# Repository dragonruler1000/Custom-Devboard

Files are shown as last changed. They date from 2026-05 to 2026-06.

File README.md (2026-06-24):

# Primortia Devboard
This is a custom rp2040 devboard that i wanted to make so i could use a custom board instead of a pico for a few projects and because i thought that it would be a fun challange and a way to test my knowlage of how to route a trace properly. sense it is PCBA the only parts that are soldered after it arrives is the pins on the edges.

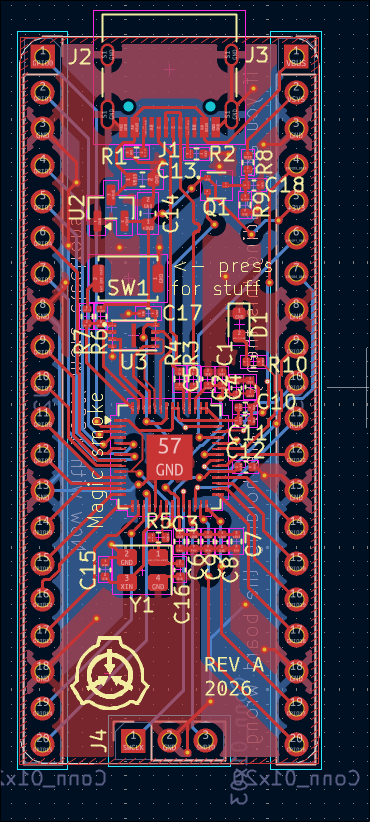
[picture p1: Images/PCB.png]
keyboard PCB


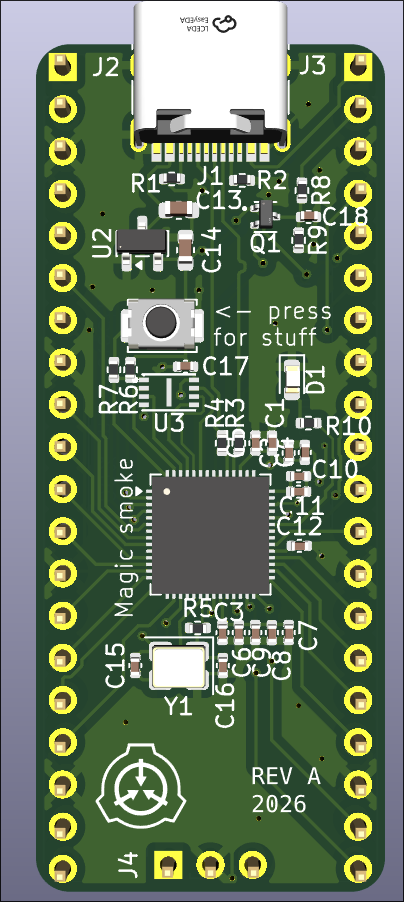
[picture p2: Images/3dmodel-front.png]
3d model front

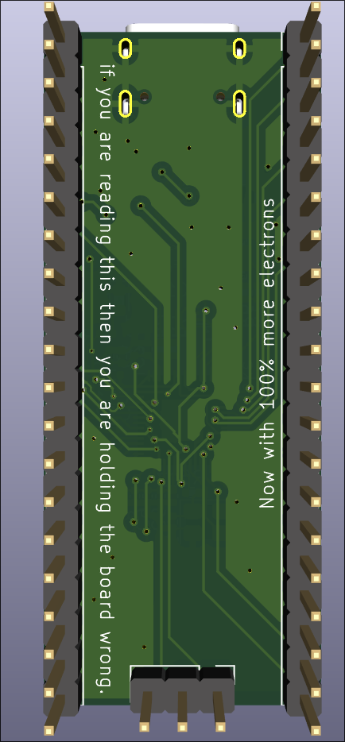
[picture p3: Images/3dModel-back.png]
3d model front


BOM:
| Item Count | item name | Unit price $ | Total Price* | Price with discounts* | Link | Running total $* | Running total with coupons* | part number | Notes |
|---|---|---|---|---|---|---|---|---|---|
| 2 | rp2040 | 0.98 | 1.96 | 1.96 | https://jlcpcb.com/partdetail/RaspberryPi-RP2040/C2040 | 2.08 | 2.08 | 1 | |
| 2 | USB-C port | 0.18 | 0.36 | 0.36 | https://jlcpcb.com/partdetail/Korean_HropartsElec-TYPE_C_31_M12/C165948  | 2.46 | 2.46 | 2 | |
| 2 | crystal oscillator | 0.07 | 0.14 | 0.14 | https://jlcpcb.com/partdetail/YXC_CrystalOscillators-X322512MSB4SI/C9002 | 2.61 | 2.61 | 3 | |
| 2 | flash memory | 0.69 | 1.38 | 1.38 | https://jlcpcb.com/partdetail/3384470-IS25WP016D_JULETR/C2976734 | 4.07 | 4.07 | 4 | |
| 2 | bush button | 0.06 | 0.12 | 0.12 | https://jlcpcb.com/partdetail/XUNPU-TS_1088AR02016/C720477 | 4.2 | 4.2 | 5 | |
| 2 | Schottky diode | 0.04 | 0.08 | 0.08 | https://jlcpcb.com/partdetail/TECHPUBLIC-DMG1012T/C2830301 | 4.28 | 4.28 | 6 | |
| 2 | LDO | 0.63 | 1.26 | 1.26 | https://jlcpcb.com/partdetail/MicrochipTech-MCP1700T_1202ETT/C144202 | 5.62 | 5.62 | 7 | |
| 4 | 1uF capacitor | 0.01 | 0.04 | 0.04 | https://jlcpcb.com/partdetail/53938-CL05A105KA5NQNC/C52923 | 5.66 | 5.66 | 8 | |
| 22 | 0.1uf capacitor | 0.01 | 0.22 | 0.22 | https://jlcpcb.com/partdetail/1877-CL05B104KO5NNNC/C1525 | 5.89 | 5.89 | 9 | |
| 4 | 33pF capacitors | 0.01 | 0.04 | 0.04 | https://jlcpcb.com/partdetail/1914-0402CG330J500NT/C1562 | 5.93 | 5.93 | 10 | |
| 2 | 1nF Capacitor | 0.01 | 0.02 | 0.02 | https://jlcpcb.com/partdetail/1875-0402B102K500NT/C1523 | 5.95 | 5.95 | 10 | |
| 4 | 10uF Capacitors | 0.01 | 0.04 | 0.04 | https://jlcpcb.com/partdetail/20411-CL10A106KP8NNNC/C19702 | 5.99 | 5.99 | 10 | |
| 2 | LED | 0.01 | 0.02 | 0.02 | https://jlcpcb.com/partdetail/CHONGTIAN-CT_1608UGCP4/C52675989 | 6.01 | 6.01 | 10 | |
| 2 | 470R Resistors | 0.01 | 0.02 | 0.02 | https://jlcpcb.com/partdetail/25860-0402WGF4700TCE/C25117 | 6.03 | 6.03 | 8 | |
| 4 | 5.1k Resistors | 0.01 | 0.04 | 0.04 | https://jlcpcb.com/partdetail/26648-0402WGF5101TCE/C25905 | 6.07 | 6.07 | 9 | |
| 4 | 1k Resistors | 0.01 | 0.04 | 0.04 | https://jlcpcb.com/partdetail/12256-0402WGF1001TCE/C11702 | 6.11 | 6.11 | 10 | |
| 4 | 27 Resistors | 0.01 | 0.04 | 0.04 | https://jlcpcb.com/partdetail/Sunway-SC0402J27R0F2ANRH/C5141043 | 6.15 | 6.15 | 8 | |
| 2 | 10K Resistors | 0.01 | 0.02 | 0.02 | https://jlcpcb.com/partdetail/26487-0402WGF1002TCE/C25744 | 6.17 | 6.17 | 9 | |
| 2 | 100K Resistors | 0.01 | 0.02 | 0.02 | https://jlcpcb.com/partdetail/26484-0402WGF1003TCE/C25741 | 6.19 | 6.19 | 10 | |
| 2 | 200K Resistors | 0.01 | 0.02 | 0.02 | https://jlcpcb.com/partdetail/26507-0402WGF2003TCE/C25764 | 6.21 | 6.21 | 10 | |
| 4 | 1x20 pin header | 1.04 | 4.16 | 4.16 | https://www.digikey.com/en/products/detail/adam-tech/PH1-20-UA/9830398 | 10.62 | 10.62 | 12 | |
| 1 | PCB | 3.1 | 3.1 | 3.1 | https://jlcpcb.com/partdetail/CHONGTIAN-CT_1608UGCP4/C52675989 | 13.91 | 13.91 | 10 | |
| 1 | PCBA – parts price | 33.65 | 33.65 | 33.65 | https://jlcpcb.com/ | 49.58 | 49.58 | 10 | |
| 1 | JLCPCB Shipping | 7.29 | 7.29 | 3 | https://jlcpcb.com/ | 57.31 | 52.76 | 10 | |
| 1 | Digikey Shipping | 6.99 | 6.99 | 6.99 | https://www.digikey.com | 64.72 | 60.17 | 10 | |
| | | | | | | | | | |
| | | | | | | | *Rounded to two decimal places | | |

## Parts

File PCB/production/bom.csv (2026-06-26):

Designator | Footprint | Quantity | Value | LCSC Part #
C1, C10 | 0402 | 2 | 1uF
C11, C12, C17, C2, C3, C4, C5, C6, C7, C8, C9 | 0402 | 11 | 0.1uF
C13, C14 | 0603 | 2 | 10uF
C15, C16 | 0402 | 2 | 33pF
C18 | 0402 | 1 | 1nf
D1 | 0603 | 1 | Green
J1 | USB_C_Receptacle_HRO_TYPE-C-31-M-12 | 1 | USB_C_Receptacle_USB2.0_14P
J2, J3 | PinHeader_1x20_P2.54mm_Vertical | 2 | Conn_01x20
J4 | PinHeader_1x03_P2.54mm_Vertical | 1 | Conn_01x03
Q1 | SOT-523 | 1 | DMG1012T
R1, R2 | 0402 | 2 | 5.1K
R10 | 0402 | 1 | 470R
R3, R4 | 0402 | 2 | 27
R5, R7 | 0402 | 2 | 1K
R6 | 0402 | 1 | 10K
R8 | 0402 | 1 | 200K
R9 | 0402 | 1 | 100K
SW1 | SW_Push_SPST_NO_Alps_SKRK | 1 | SW_Push
U1 | QFN-56-1EP_7x7mm_P0.4mm_EP3.2x3.2mm | 1 | RP2040
U2 | SOT-23 | 1 | MCP1700x-120xxMB
U3 | USON-8_L3.0-W2.0-P0.50-BL-EP | 1 | W25Q128JVS | C2843335
Y1 | Crystal_SMD_3225-4Pin_3.2x2.5mm | 1 | 12MHz

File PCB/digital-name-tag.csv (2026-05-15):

Id | Designator | Footprint | Quantity | Designation | Supplier and ref
1 | C10,C1 | C_0402_1005Metric | 2 | 1uF
2 | C7,C8,C3,C6,C5,C11,C12,C2,C9,C17,C4 | C_0402_1005Metric | 11 | 0.1uF
3 | Y1 | Crystal_SMD_3225-4Pin_3.2x2.5mm | 1 | 12MHz
4 | R7,R5 | R_0402_1005Metric | 2 | 1K
5 | U1 | QFN-56-1EP_7x7mm_P0.4mm_EP3.2x3.2mm | 1 | RP2040
6 | R4,R3 | R_0402_1005Metric | 2 | 27
7 | SW1 | SW_Push_SPST_NO_Alps_SKRK | 1 | SW_Push
8 | R6 | R_0402_1005Metric | 1 | 10K
9 | C15,C16 | C_0402_1005Metric | 2 | 33pF
10 | R10 | R_0402_1005Metric | 1 | 470R
11 | U2 | SOT-23 | 1 | MCP1700x-120xxMB
12 | J4 | PinHeader_1x03_P2.54mm_Vertical | 1 | Conn_01x03
13 | Q1 | SOT-523 | 1 | DMG1012T
14 | R2,R1 | R_0402_1005Metric | 2 | 5.1K
15 | D1 | LED_0603_1608Metric | 1 | LED
16 | C18 | C_0402_1005Metric | 1 | 1nf
17 | C14,C13 | C_0603_1608Metric | 2 | 10uF
18 | J1 | USB_C_Receptacle_HRO_TYPE-C-31-M-12 | 1 | USB_C_Receptacle_USB2.0_14P
19 | J2,J3 | PinHeader_1x20_P2.54mm_Vertical | 2 | Conn_01x20
20 | U3 | USON-8_L3.0-W2.0-P0.50-BL-EP | 1 | W25Q128JVS
21 | R8 | R_0402_1005Metric | 1 | 200K
22 | R9 | R_0402_1005Metric | 1 | 100K

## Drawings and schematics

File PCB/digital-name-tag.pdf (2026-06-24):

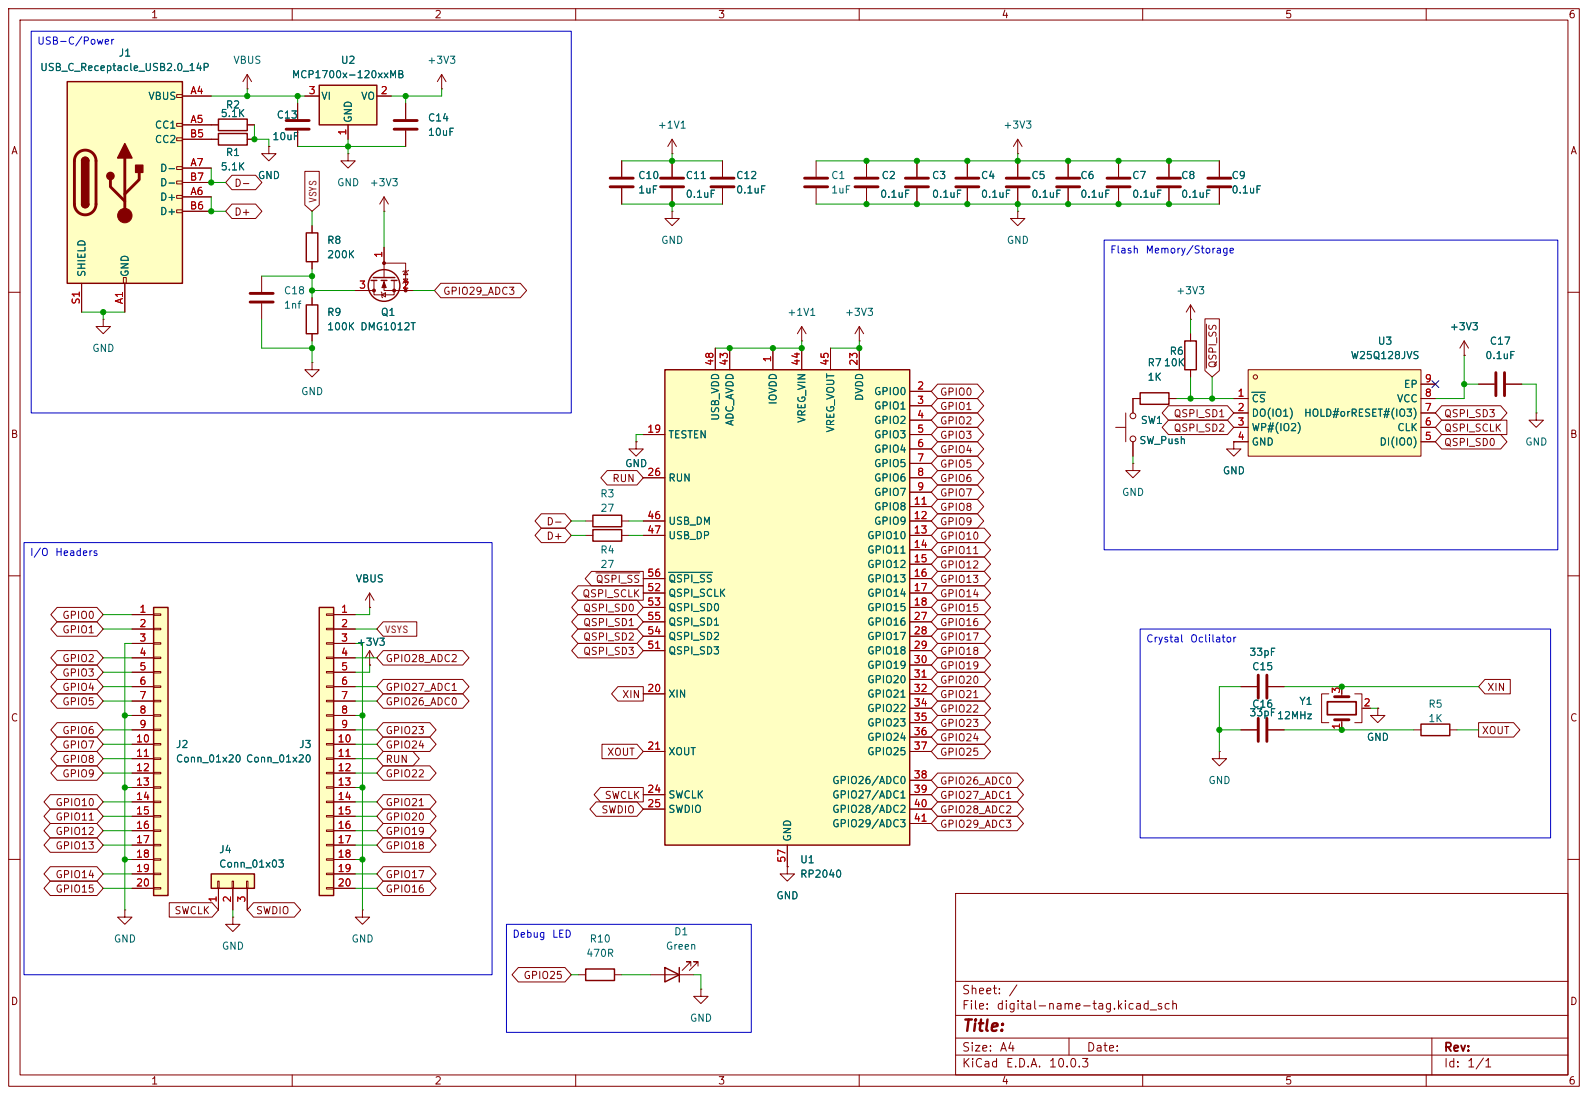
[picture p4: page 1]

3 U3 W25Q128JVS CS 1 DO(IO1) 2 WP#(IO2) 3 GND 4 DI(IO0) 5 CLK 6 HOLD#orRESET#(IO3) 7

Sheet: /
File: digital-name-tag.kicad_sch
Title:

Size: A4 | Rev:
KiCad E.D.A. 10.0.3 | Id: 1/1

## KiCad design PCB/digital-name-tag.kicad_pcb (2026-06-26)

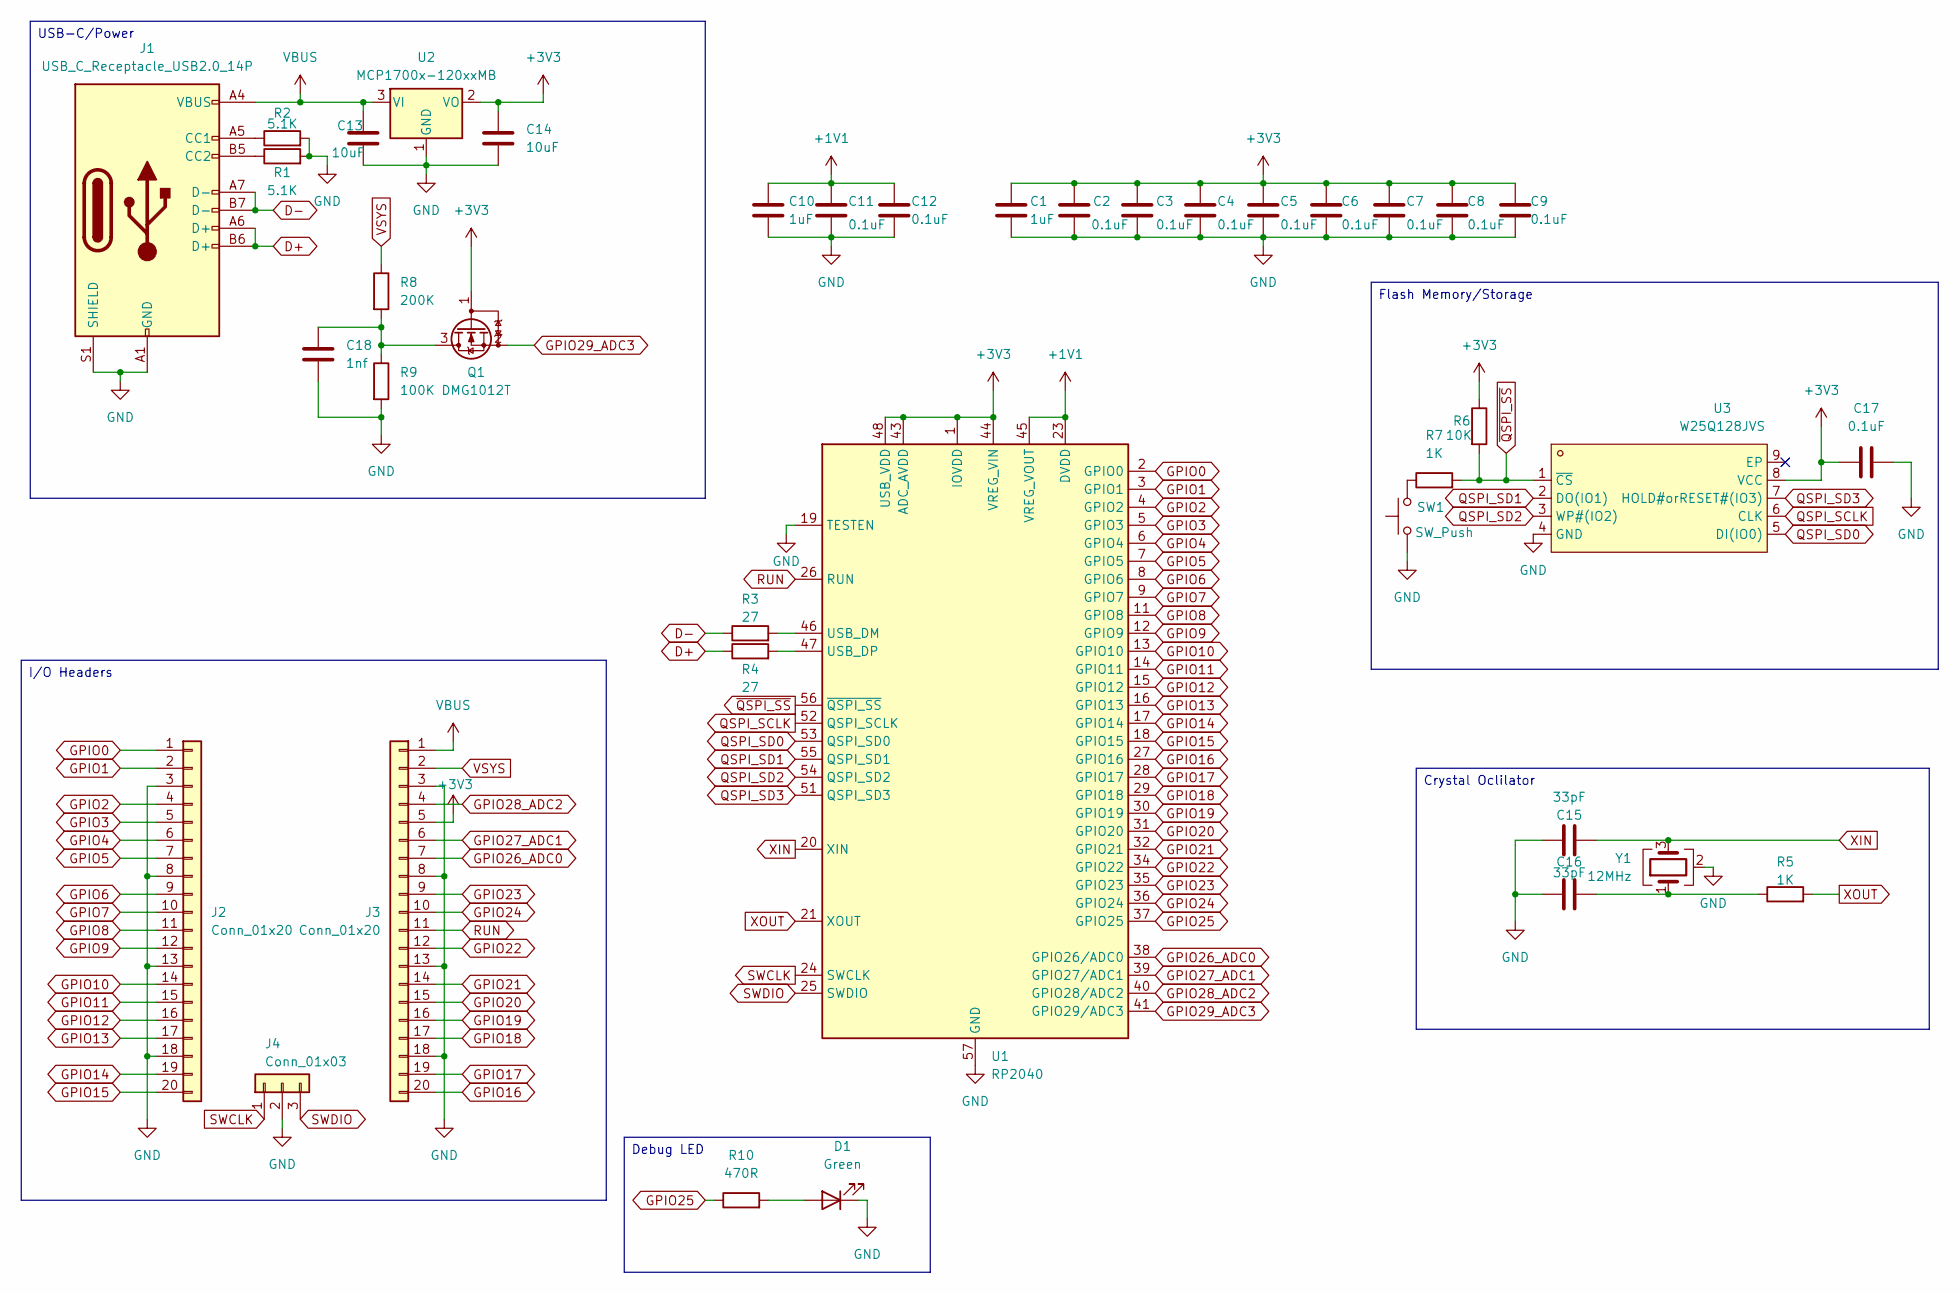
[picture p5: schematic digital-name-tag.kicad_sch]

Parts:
C1, C10: 1uF; C_0402_1005Metric
C2, C3, C4, C5, C6, C7, C8, C9, C11, C12, C17: 0.1uF; C_0402_1005Metric
C13, C14: 10uF; C_0603_1608Metric
C15, C16: 33pF; C_0402_1005Metric; lcsc part # C1663
C18: 1nf; C_0402_1005Metric
D1: Green; LED_0603_1608Metric
J1: USB_C_Receptacle_USB2.0_14P; USB_C_Receptacle_HRO_TYPE-C-31-M-12
J2, J3: Conn_01x20; PinHeader_1x20_P2.54mm_Vertical
J4: Conn_01x03; PinHeader_1x03_P2.54mm_Vertical
Q1: DMG1012T; SOT-523
R1, R2: 5.1K; R_0402_1005Metric
R3, R4: 27; R_0402_1005Metric
R5, R7: 1K; R_0402_1005Metric
R6: 10K; R_0402_1005Metric
R8: 200K; R_0402_1005Metric; lcsc part # C22369193
R9: 100K; R_0402_1005Metric
R10: 470R; R_0402_1005Metric
SW1: SW_Push; SW_Push_SPST_NO_Alps_SKRK
U1: RP2040; QFN-56-1EP_7x7mm_P0.4mm_EP3.2x3.2mm
U2: MCP1700x-120xxMB; SOT-23
U3: W25Q128JVS; USON-8_L3.0-W2.0-P0.50-BL-EP; MPN W25Q16JVUXIQ; LCSC Part C2843335
Y1: 12MHz; Crystal_SMD_3225-4Pin_3.2x2.5mm; lcsc part # C9002

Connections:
+1V1: C10.1, C11.1, C12.1, U1.23 (DVDD), U1.45 (VREG_VOUT), U1.50 (DVDD)
+3V3: C1.1, C2.1, C3.1, C4.1, C5.1, C6.1, C7.1, C8.1, C9.1, C14.1, C17.1, J3.5, Q1.1 (G), R6.1, U1.1 (IOVDD), U1.10 (IOVDD), U1.22 (IOVDD), U1.33 (IOVDD), U1.42 (IOVDD), U1.43 (ADC_AVDD), U1.44 (VREG_VIN), U1.48 (USB_VDD), U1.49 (IOVDD), U2.2 (VO), U3.8 (VCC)
D+: J1.A6 (D+), J1.B6 (D+), R4.1
D-: J1.A7 (D-), J1.B7 (D-), R3.1
GND: C1.2, C2.2, C3.2, C4.2, C5.2, C6.2, C7.2, C8.2, C9.2, C10.2, C11.2, C12.2, C13.2, C14.2, C15.1, C16.1, C17.2, C18.2, D1.1 (K), J1.A1 (GND), J1.A12 (GND), J1.B1 (GND), J1.B12 (GND), J1.S1 (SHIELD), J2.3, J2.8, J2.13, J2.18, J3.3, J3.8, J3.13, J3.18, J4.2, R1.2, R2.2, R9.2, SW1.1, U1.19 (TESTEN), U1.57 (GND), U2.1 (GND), U3.4 (GND), Y1.2 (G), Y1.4 (G)
GPIO0: J2.1, U1.2 (GPIO0)
GPIO1: J2.2, U1.3 (GPIO1)
GPIO2: J2.4, U1.4 (GPIO2)
GPIO3: J2.5, U1.5 (GPIO3)
GPIO4: J2.6, U1.6 (GPIO4)
GPIO5: J2.7, U1.7 (GPIO5)
GPIO6: J2.9, U1.8 (GPIO6)
GPIO7: J2.10, U1.9 (GPIO7)
GPIO8: J2.11, U1.11 (GPIO8)
GPIO9: J2.12, U1.12 (GPIO9)
GPIO10: J2.14, U1.13 (GPIO10)
GPIO11: J2.15, U1.14 (GPIO11)
GPIO12: J2.16, U1.15 (GPIO12)
GPIO13: J2.17, U1.16 (GPIO13)
GPIO14: J2.19, U1.17 (GPIO14)
GPIO15: J2.20, U1.18 (GPIO15)
GPIO16: J3.20, U1.27 (GPIO16)
GPIO17: J3.19, U1.28 (GPIO17)
GPIO18: J3.17, U1.29 (GPIO18)
GPIO19: J3.16, U1.30 (GPIO19)
GPIO20: J3.15, U1.31 (GPIO20)
GPIO21: J3.14, U1.32 (GPIO21)
GPIO22: J3.12, U1.34 (GPIO22)
GPIO23: J3.9, U1.35 (GPIO23)
GPIO24: J3.10, U1.36 (GPIO24)
GPIO25: R10.1, U1.37 (GPIO25)
GPIO26_ADC0: J3.7, U1.38 (GPIO26/ADC0)
GPIO27_ADC1: J3.6, U1.39 (GPIO27/ADC1)
GPIO28_ADC2: J3.4, U1.40 (GPIO28/ADC2)
GPIO29_ADC3: Q1.2 (S), U1.41 (GPIO29/ADC3)
unnamed: C16.2, R5.1, Y1.1
unnamed: D1.2 (A), R10.2
unnamed: J1.A5 (CC1), R2.1
unnamed: J1.B5 (CC2), R1.1
unnamed: C18.1, Q1.3 (D), R8.2, R9.1
unnamed: R7.1, SW1.2
unnamed: R3.2, U1.46 (USB_DM)
unnamed: R4.2, U1.47 (USB_DP)
QSPI_SCLK: U1.52 (QSPI_SCLK), U3.6 (CLK)
QSPI_SD0: U1.53 (QSPI_SD0), U3.5 (DI(IO0))
QSPI_SD1: U1.55 (QSPI_SD1), U3.2 (DO(IO1))
QSPI_SD2: U1.54 (QSPI_SD2), U3.3 (WP#(IO2))
QSPI_SD3: U1.51 (QSPI_SD3), U3.7 (HOLD#orRESET#(IO3))
RUN: J3.11, U1.26 (RUN)
SWCLK: J4.1, U1.24 (SWCLK)
SWDIO: J4.3, U1.25 (SWDIO)
VBUS: C13.1, J1.A4 (VBUS), J1.A9 (VBUS), J1.B4 (VBUS), J1.B9 (VBUS), J3.1, U2.3 (VI)
VSYS: J3.2, R8.1
XIN: C15.2, U1.20 (XIN), Y1.3
XOUT: R5.2, U1.21 (XOUT)
~QSPI_SS: R6.2, R7.2, U1.56 (~QSPI_SS), U3.1 (~CS)

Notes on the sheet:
Flash Memory/Storage
USB-C/Power
Debug LED
Crystal Oclilator
I/O Headers

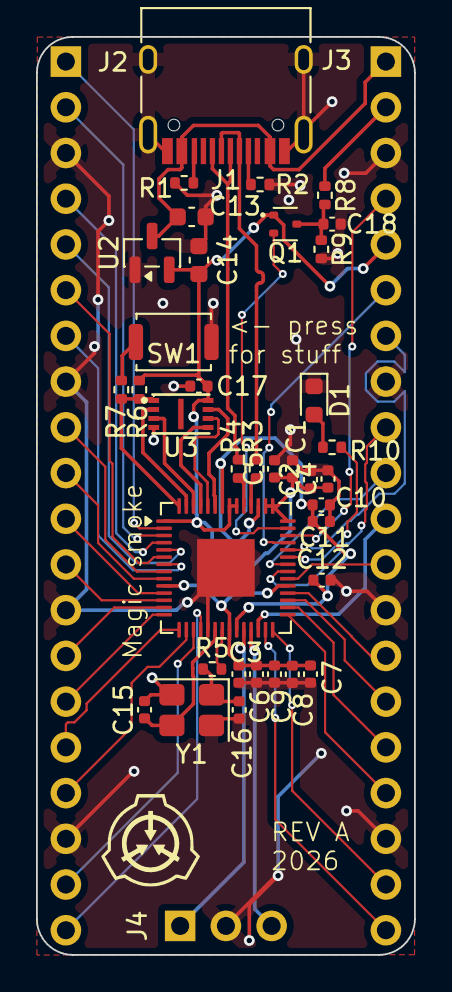
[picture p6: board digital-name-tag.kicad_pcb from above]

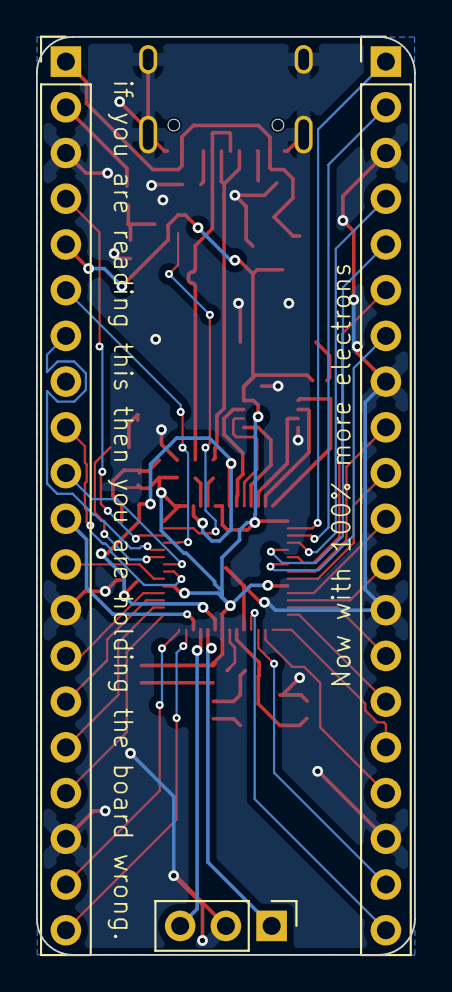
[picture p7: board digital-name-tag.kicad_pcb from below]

Board: 2 copper layers, 21.0 x 51.0 mm, 39 parts (3 on the bottom side), 56 nets.

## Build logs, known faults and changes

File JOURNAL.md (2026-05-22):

# May 5th, 2026: Got started on the schematic

Got started on making the devboard part of the project. i am making a custom rp2040 devboard that will slot into the base/main pcb of the name tag.

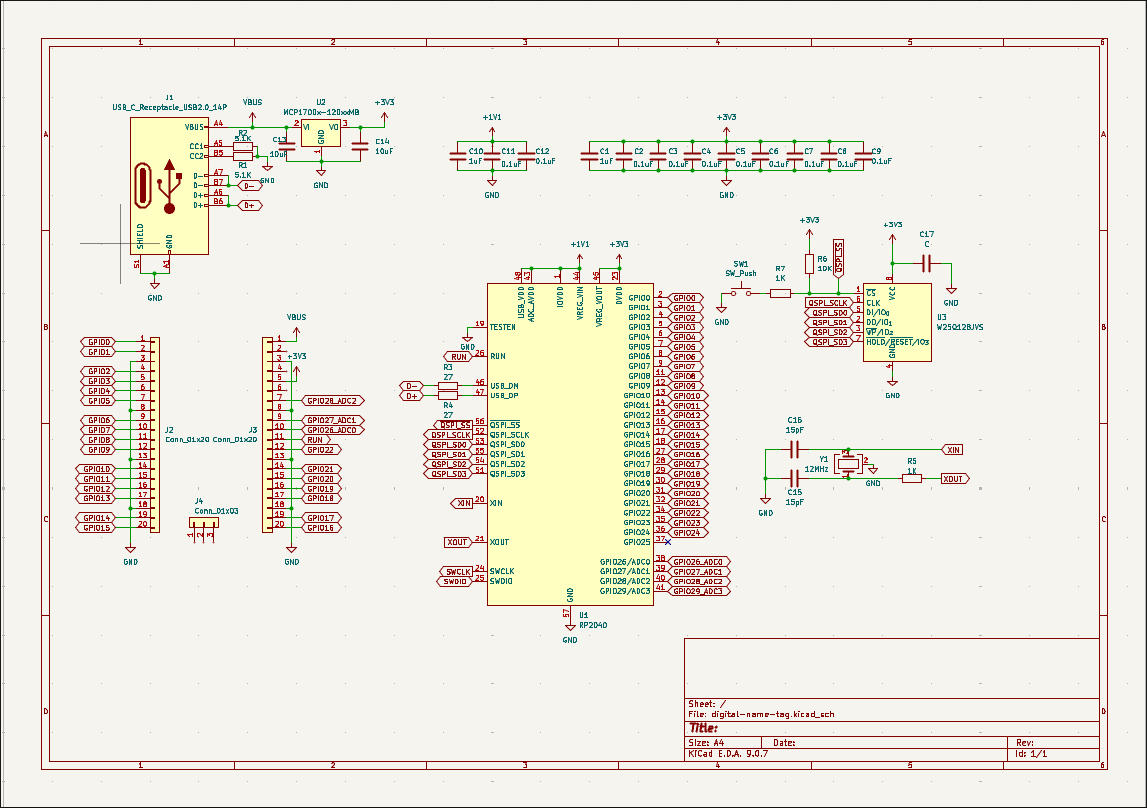
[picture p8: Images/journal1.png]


**Total time spent: 2h**

# May 6th, 2026: finnished the schematic

I figured out how to use a battery to power the rp2040 and finished connecting all the nets where they need to go. i also got all of the foot prints assigned.

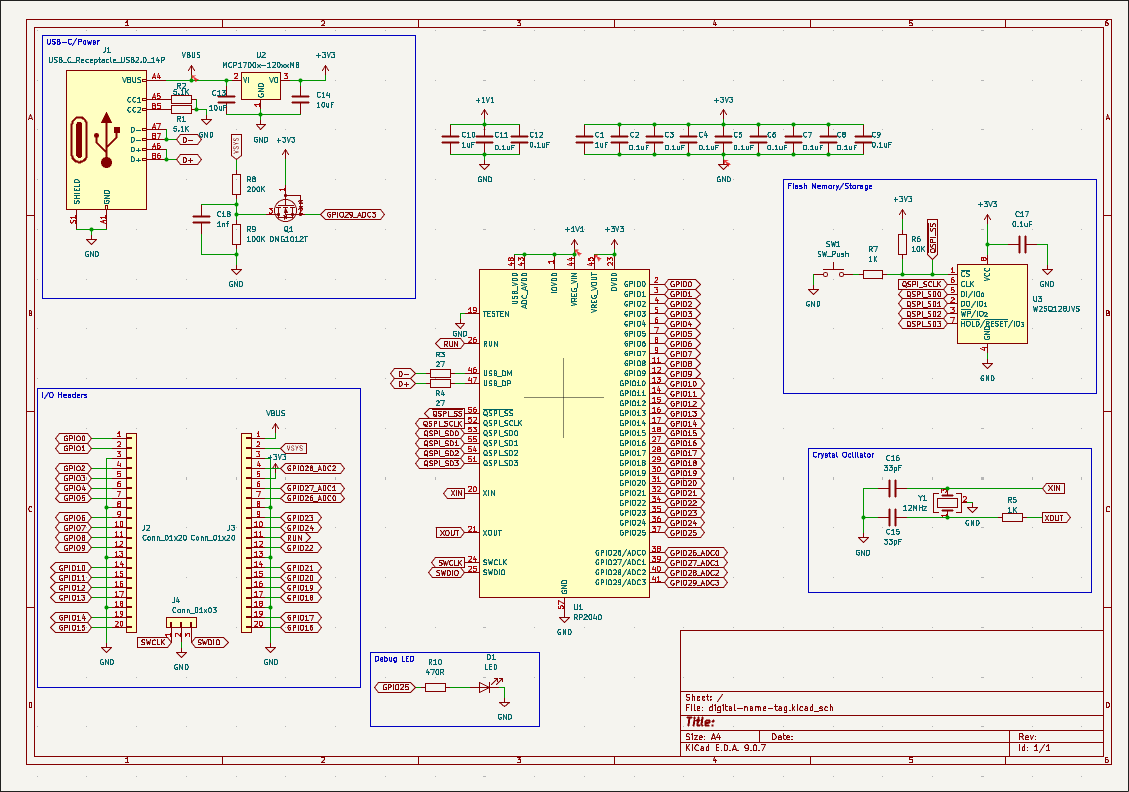
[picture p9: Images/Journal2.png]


**Total time spent: 1.5h**

# May 7th, 2026: Started placing the footprints
Start time: 19:50
I decided to switch from having the custom devboard and the name tag be two seperate projects so i wouldnt have to worry about how i will order the pcbs. I got a bunch of footprints placed though fine tuning will be needed after i've gotten everything placed and started routing. i'm going with the storage chip that is on the hardware design with the rp2040 document just because it is the easiest to work with rather then trying to see if the one swaped to on the guide (custom devbaord guide from blueptint) gets back in stock before i order.

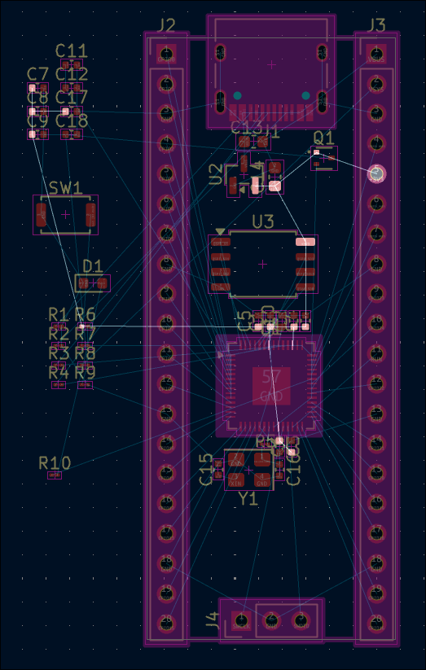
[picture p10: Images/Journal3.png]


**Total time spent: 1h**

# May 14, 2026 Pt1: Finished layout and started on routing

i got around to working on this again and got the layout done. i have mostly got routing done and am now just working on fixing DRC errors. I don't really have much more to say other then working out wards from the rp2040 is a lot easier then working in towards the rp2040.

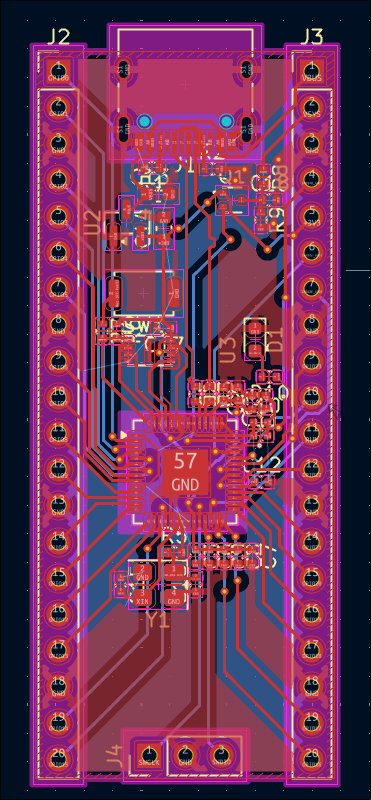
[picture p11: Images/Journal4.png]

**Total Time Spend: 4h**
# May 14th, 2026 Pt2: Fixed the DRC errors and put together BOM

I went though and fixed all of the DRC errors which was mostly just making sure that the ground plane got connected to everything that needed it and that the ground plane was connected everywhere. I also set up my BOM so now i have all the prices for the indivsual parts and shipping for the one part that is coming from digikey sense getting it from lcsc is going to cost more in shipping then i save on a slightly cheaper part.

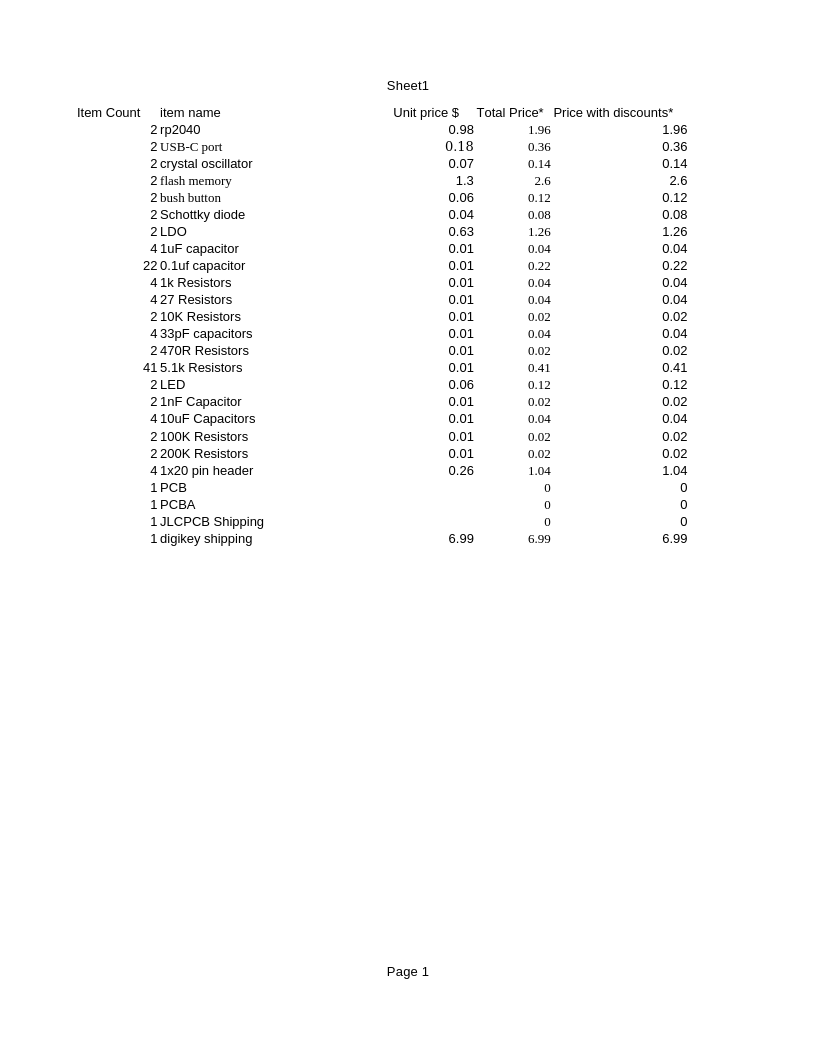
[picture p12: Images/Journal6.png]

**Time spent: 4h**

# May 16th, 2026: Finished BOM and added PCB order to cart

I got around to finishing the BOM and get the price of the pcb from JLCPCB. getting the PCB added to my cart was fun though sense i basicly had add the parts from scratch to the bom which wasn't to bad sense that did help me reduce cost because JLCPCB did sudject basic parts that fit what i needed then i also had to adjust the placement of the of the componesnts sense the rotation was off for a couple of them and the rotation and placement of the usb-c port was off so i needed to fix that at least the fabrication output plugin for kicad made it quicker still.

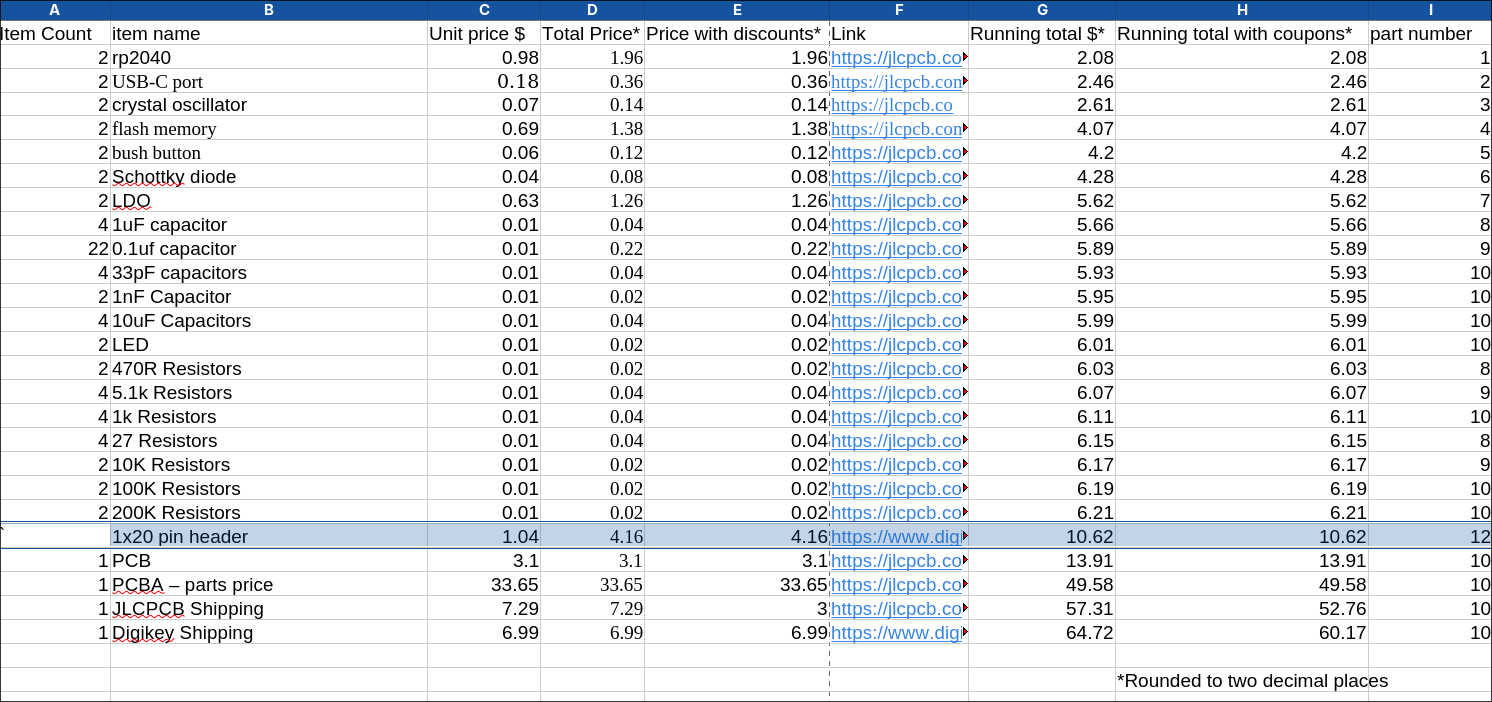
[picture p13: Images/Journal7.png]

**time spent: 1h**

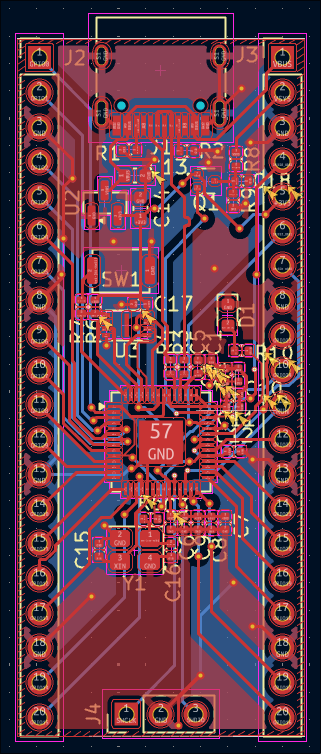
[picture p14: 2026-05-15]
Images/Journal5.png

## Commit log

2026-05-06 started on project
    [digital-name-tag.kicad_pcb, digital-name-tag.kicad_sch]
2026-05-06 finished seting up the schematic and assigned all the footprints
    [digital-name-tag.kicad_sch]
2026-05-08 startet placing footpints and updated limage links for JOURNAL.md
    [digital-name-tag.kicad_pcb, digital-name-tag.kicad_sch]
2026-05-14 finnished layout and mostly got routing done
    [digital-name-tag.kicad_pcb, digital-name-tag.kicad_sch]
2026-05-15 fixed DRC errors
    [digital-name-tag.csv, digital-name-tag.kicad_pcb, digital-name-tag.kicad_sch]
2026-05-15 put togeather BOM
    [BOM.ods, bom.csv, designators.csv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]
2026-05-16 fixed BOM and got the pcb added to cart I think i forgot to save the BOM last time but i ended up changing a good portion of it anyways to change from exstended pcba to basic.
    [BOM.csv, BOM.ods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]
2026-05-22 fileted the corners.
    [BOM.ods, digital-name-tag.kicad_pcb]
2026-05-22 added silkscreen art
    [digital-name-tag-B_Cu.gbr, digital-name-tag-B_Mask.gbr, digital-name-tag-B_Paste.gbr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]
2026-05-25 updated gerbers
    [bom.xls]
2026-06-24 updated the schematic and pcb to have the correct power rails.
    [digital-name-tag.kicad_pcb, digital-name-tag.kicad_sch]
2026-06-26 made the production files
    [bom.csv, designators.csv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]
